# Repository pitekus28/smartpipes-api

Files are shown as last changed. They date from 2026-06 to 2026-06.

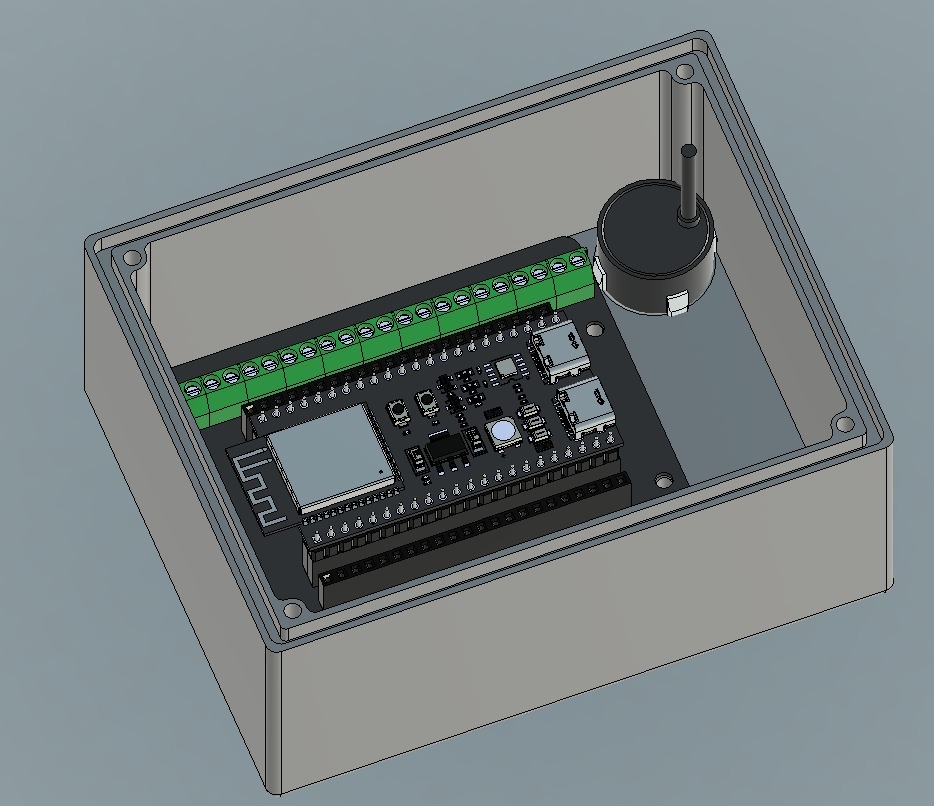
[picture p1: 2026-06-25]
Diseño-3D/Renders/Imagen 2.png

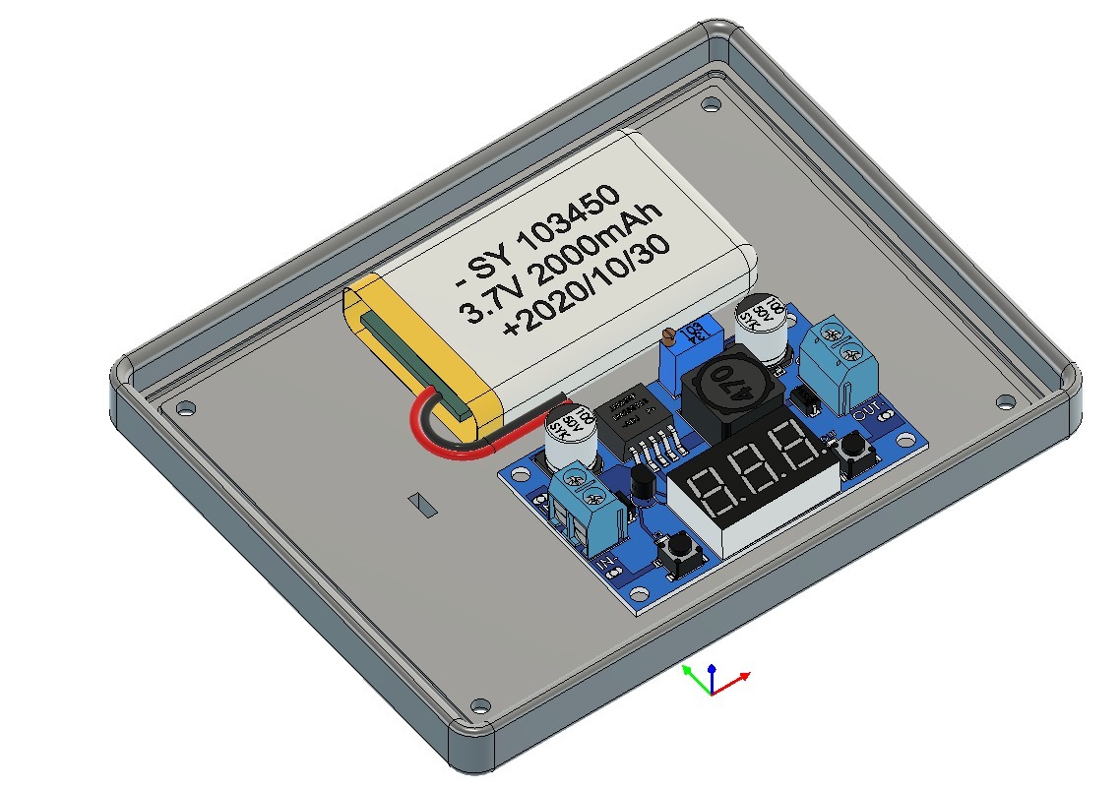
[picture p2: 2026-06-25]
Diseño-3D/Renders/Imagen 3.png

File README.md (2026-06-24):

# SmartPipes

SmartPipes es un prototipo IoT para el monitoreo preventivo de alcantarillados. El sistema mide la distancia física entre el sensor y el nivel de agua, sedimento u obstrucción dentro de una alcantarilla, calcula un porcentaje de llenado, detecta humedad y envía los datos a una base de datos en la nube para visualizarlos en un dashboard web.

## Integrantes

* Javier Fuentes
* Diego Fuentes
* Ignacio Tajmuch
* Felipe Madariaga

## Problema que resuelve

Las obstrucciones en alcantarillados pueden generar rebalses, malos olores, inundaciones y problemas sanitarios. SmartPipes busca detectar acumulación o riesgo de obstrucción de forma temprana mediante sensores instalados en el interior de una alcantarilla.

## Arquitectura del sistema

El flujo del sistema es:

ESP32-S3 → Railway API → Aiven PostgreSQL → Dashboard Web

La ESP32 captura datos del entorno, calcula indicadores y los envía por WiFi a una API desplegada en Railway. La API almacena los datos en una base de datos PostgreSQL en Aiven. El dashboard web permite visualizar el estado actual del sensor y el histórico de mediciones.

## Componentes principales

* ESP32-S3 N16R8
* Sensor ultrasónico impermeable SR04M-2 / AJ-SR04M
* Sensor de humedad/lluvia MH-RD Raindrops Sensor de 2 pines
* Batería LiPo 3.7V 2000mAh
* Módulo Step-Up DC-DC 3.7V a 5V
* Resistencia 10kΩ para pull-down del sensor de humedad
* Cables Dupont
* Protoboard o base de conexión interna

## Sensores y pines usados

### Sensor ultrasónico SR04M-2 / AJ-SR04M

* 5V → 5V/VIN ESP32
* GND → GND ESP32
* TX → GPIO18 ESP32
* RX → Sin conectar

### Sensor humedad MH-RD 2 pines

* Un pin del sensor → 3V3 ESP32
* Otro pin del sensor → GPIO4 ESP32
* GPIO4 → resistencia 10kΩ → GND

## Calibración usada

La alcantarilla se calibró considerando:

* 100 cm o más: alcantarilla limpia, 0% de llenado.
* 20 cm o menos: alcantarilla casi tapada, 100% de llenado.

El porcentaje de llenado se calcula con la distancia física medida por el sensor ultrasónico.

## Estados del sistema

* NORMAL: 0% a 19%
* ATENCION: 20% a 39%
* ALERTA: 40% a 59%
* RIESGO: 60% a 74%
* CRITICO: 75% a 89%
* EMERGENCIA: 90% a 100%

## Dashboard

Dashboard web:

https://smartpipes-api-production.up.railway.app

El dashboard permite visualizar:

* Estado actual del sensor
* Distancia física medida
* Porcentaje de llenado
* Humedad detectada
* Batería
* Histórico mensual
* Gráficas de porcentaje de llenado

## Instrucciones de uso

1. Encender la base de datos Aiven.
2. Activar el deployment en Railway.
3. Conectar la ESP32 a energía.
4. Verificar en el monitor serial que aparezca `Codigo respuesta API: 200`.
5. Abrir el dashboard web.
6. Observar las mediciones en tiempo real.

## Estructura del repositorio

* `firmware/`: código de la ESP32.
* `hardware/`: esquemático, BOM y fotografías del montaje.
* `diseño-3d/`: archivos de Fusion 360, STL, planos y renders.
* `testing/`: protocolo de pruebas, resultados, logs y capturas.
* `docs/`: documentación del proyecto.
* `public/`: dashboard web.
* `server.js`: API backend.

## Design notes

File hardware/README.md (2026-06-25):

# Hardware — SmartPipes

## Descripción

Esta carpeta contiene la documentación del hardware del proyecto SmartPipes. Aquí se incluyen los componentes utilizados en el prototipo, el esquemático de conexiones y la información necesaria para comprender cómo fue implementado físicamente el sistema.

El hardware fue diseñado para capturar datos reales del entorno mediante sensores, procesarlos con una ESP32-S3 y alimentar el sistema de forma portátil, manteniendo una arquitectura coherente con el problema abordado: el monitoreo preventivo de ductos y alcantarillados.

---

## Contenido de la carpeta

### 1. BOM (Bill of Materials)

La lista de materiales resume los componentes utilizados para construir el prototipo, junto con su cantidad, especificación, función y costo aproximado.

Incluye elementos principales como:

* ESP32-S3 N16R8
* sensor ultrasónico impermeable AJ-SR04M / SR04M
* sensor de humedad MH-RD
* batería LiPo
* módulo Step-Up DC-DC
* cables, resistencia pull-down, tornillos y materiales de fabricación

La BOM permite estimar el costo total del prototipo y documentar la viabilidad de replicación del sistema.

### 2. Esquemático de conexiones

El esquemático documenta la conexión entre la ESP32-S3, los sensores y el sistema de alimentación.

Se detallan:

* alimentación desde batería LiPo hacia el módulo Step-Up
* entrega de 5V a la ESP32 y al sensor ultrasónico
* lectura del sensor ultrasónico mediante GPIO18
* lectura del sensor de humedad mediante GPIO4
* uso de resistencia pull-down de 10kΩ para evitar falsos positivos en el sensor de humedad
* conexión común de tierras (GND) en todo el sistema

---

## Arquitectura de hardware

El sistema físico se compone de tres subsistemas principales:

### 1. Control y procesamiento

La **ESP32-S3 N16R8** actúa como controlador principal. Se encarga de:

* leer los sensores,
* calcular el porcentaje de llenado,
* clasificar el estado del ducto,
* y enviar los datos al sistema web mediante WiFi.

### 2. Sensado

El prototipo utiliza dos sensores:

* **AJ-SR04M / SR04M-2**: mide la distancia física al fondo del ducto o a una obstrucción.
* **MH-RD Raindrops**: detecta humedad o presencia de agua como variable complementaria.

La elección del sensor ultrasónico impermeable fue especialmente importante para hacer coherente el sistema con un contexto húmedo o expuesto al agua.

### 3. Alimentación

La energía del sistema proviene de una **batería LiPo de 3.7V**, cuyo voltaje es elevado mediante un **módulo Step-Up DC-DC** para alimentar correctamente la ESP32 y el sensor ultrasónico.

---

## Consideraciones técnicas importantes

### Sensor de humedad

El sensor MH-RD requiere una **resistencia pull-down de 10kΩ** entre GPIO4 y GND. Esta resistencia evita que el pin quede flotando, lo que podría generar lecturas falsas de humedad.

### Sensor ultrasónico

El sensor AJ-SR04M fue elegido por su mayor pertinencia para un sistema expuesto a agua o humedad, en comparación con sensores ultrasónicos más básicos como el HC-SR04.

### GND común

Todos los negativos del sistema deben compartir tierra común:

* GND de la ESP32
* GND del sensor ultrasónico
* negativo de batería
* salida negativa del Step-Up
* GND de la resistencia pull-down

Esto es fundamental para asegurar lecturas estables y un funcionamiento correcto del sistema.

---

## Justificación general del hardware

Los componentes seleccionados permiten construir un prototipo funcional, portátil y técnicamente coherente con el problema del proyecto. El sistema combina:

* procesamiento con conectividad WiFi,
* medición física de nivel u obstrucción,
* detección complementaria de humedad,
* y alimentación autónoma mediante batería.

Además, el montaje fue pensado para integrarse dentro de un encapsulado fabricado en 3D, con fijaciones desmontables y acceso a componentes internos para reparación o ajuste.

---

## Archivos esperados en esta carpeta

* `BOM.md`, `BOM.xlsx` o equivalente
* `esquematico.pdf` o imagen del esquemático
* fotografías del prototipo ensamblado
* documentación complementaria de conexiones si aplica

---

## Observaciones

La documentación contenida en esta carpeta permite entender, replicar y justificar la implementación física del prototipo SmartPipes dentro del contexto del curso TEI201.

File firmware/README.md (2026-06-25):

# Firmware — SmartPipes

## Descripción

Esta carpeta contiene el firmware principal del sistema SmartPipes. El programa está desarrollado para una **ESP32-S3** y se encarga de capturar datos del entorno, procesarlos y enviarlos a la nube para su visualización en un dashboard web.

El firmware mide la distancia interna de un ducto mediante un sensor ultrasónico impermeable, detecta presencia de humedad, calcula el porcentaje de llenado y clasifica el estado del sistema según niveles de riesgo.

---

## Funciones principales del firmware

El código implementa las siguientes tareas:

* conexión de la ESP32 a una red WiFi
* lectura del sensor ultrasónico AJ-SR04M / SR04M-2
* filtrado básico mediante promedio de múltiples lecturas
* lectura del sensor de humedad MH-RD
* cálculo del porcentaje de llenado del ducto
* clasificación del estado del sistema
* impresión de resultados en el monitor serial
* envío de datos en formato JSON a una API desplegada en Railway

---

## Variables que genera el sistema

El firmware obtiene y procesa las siguientes variables:

* **distancia_cm**: distancia medida entre el sensor y el fondo u obstrucción
* **porcentaje_lleno**: estimación del nivel de llenado del ducto
* **humedad**: presencia o ausencia de humedad detectada
* **estado**: clasificación del ducto según el nivel de riesgo
* **bateria_voltaje**: valor de batería enviado como referencia

---

## Calibración utilizada

La lógica del sistema utiliza dos referencias físicas:

* **100 cm o más** → ducto limpio → **0% lleno**
* **20 cm o menos** → ducto casi tapado → **100% lleno**

Con esto, el firmware transforma una distancia física en una estimación de llenado útil para interpretar el estado del ducto.

---

## Estados definidos

El sistema clasifica el ducto en los siguientes niveles:

| Estado | Interpretación |
| --- | --- |
| NORMAL | Ducto despejado  |
| ATENCION | Acumulación leve |
| ALERTA | Posible bloqueo  |
| RIESGO | Obstrucción alta |
| CRITICO | Casi colapsado |
| EMERGENCIA | Tapado total |
| ERROR | Falla de sensor  |

---

## Hardware esperado por el firmware

### Microcontrolador

* ESP32-S3 N16R8

### Sensor ultrasónico

* AJ-SR04M / SR04M-2

### Sensor de humedad

* MH-RD Raindrops de 2 pines

### Otros elementos

* resistencia pull-down de 10kΩ
* batería LiPo 3.7V
* módulo Step-Up DC-DC 3.7V a 5V

---

## Pines utilizados

### Sensor ultrasónico

* `GPIO18` → señal del sensor ultrasónico

### Sensor de humedad

* `GPIO4` → lectura del sensor MH-RD

---

## Flujo de funcionamiento

1. La ESP32 se conecta a WiFi.
2. El sensor ultrasónico mide la distancia.
3. El sistema calcula el porcentaje de llenado.
4. El sensor de humedad detecta presencia de agua o conducción.
5. Se evalúa el estado del ducto.
6. Los datos se imprimen en el monitor serial.
7. Se envían a la API en Railway.
8. El ciclo se repite aproximadamente cada 10 segundos.

---

## Servicios externos utilizados

El firmware está preparado para trabajar con:

* una **API en Railway**
* una **base de datos PostgreSQL en Aiven**
* un **dashboard web SmartPipes**

---

## Cómo cargar el firmware

1. Abrir el archivo `.ino` en Arduino IDE.
2. Seleccionar la placa ESP32 correspondiente.
3. Revisar las credenciales de WiFi y la URL de la API.
4. Verificar la conexión de sensores y alimentación.
5. Cargar el código en la ESP32.
6. Abrir el monitor serial a **115200 baudios** para revisar el funcionamiento.

---

## Archivos esperados en esta carpeta

* `smart_pipes.ino` o archivo principal equivalente
* este `README.md`

---

## Observaciones

El firmware fue adaptado para el uso de un sensor ultrasónico impermeable, más coherente con el contexto del proyecto, orientado al monitoreo de ductos y alcantarillas con posible presencia de humedad o agua.

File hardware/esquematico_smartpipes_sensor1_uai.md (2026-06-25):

smartpipes_sensor1_UAI_esquematico_final
# Esquemático de conexiones SmartPipes

## ESP32-S3 N16R8

La ESP32-S3 es el controlador principal del sistema. Lee los sensores, calcula el porcentaje de llenado y envía los datos al dashboard web mediante WiFi.

## Alimentación

| Componente | Pin | Conexión |
|---|---|---|
| Batería LiPo 3.7V | + | IN+ Step-Up |
| Batería LiPo 3.7V | - | IN- Step-Up |
| Step-Up DC-DC | OUT+ 5V | 5V/VIN ESP32 |
| Step-Up DC-DC | OUT- GND | GND ESP32 |

## Sensor ultrasónico SR04M-2 / AJ-SR04M

| Pin sensor | Conexión |
|---|---|
| 5V | 5V/VIN ESP32 |
| GND | GND ESP32 |
| TX | GPIO18 ESP32 |
| RX | Sin conectar |

## Sensor humedad MH-RD Raindrops 2 pines

| Pin / elemento | Conexión |
|---|---|
| Pin 1 sensor humedad | 3V3 ESP32 |
| Pin 2 sensor humedad | GPIO4 ESP32 |
| Resistencia 10kΩ | Entre GPIO4 y GND |

## Nota importante

Todos los GND del sistema deben estar conectados en común:

- GND ESP32
- GND del sensor ultrasónico
- OUT- del Step-Up
- Negativo de batería
- GND de la resistencia pull-down

## Diagrama simplificado

```txt
Batería LiPo 3.7V
        |
        v
Step-Up DC-DC 3.7V a 5V
        |
        v
ESP32-S3 N16R8
        |
        |-- GPIO18 -> TX Sensor ultrasónico SR04M-2
        |-- 5V/VIN -> 5V Sensor ultrasónico
        |-- GND    -> GND Sensor ultrasónico
        |
        |-- GPIO4  -> Sensor humedad MH-RD
        |-- 3V3    -> Sensor humedad MH-RD
        |-- GPIO4  -> Resistencia 10kΩ -> GND

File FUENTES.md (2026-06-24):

# FUENTES.md

Este documento declara las librerías, plataformas, herramientas externas y uso de inteligencia artificial utilizados en el desarrollo del prototipo SmartPipes.

## Librerías utilizadas

| Librería | Uso en el proyecto | Fuente |
|---|---|---|
| WiFi.h | Conexión WiFi de la ESP32 | Librería incluida en el core de ESP32 para Arduino |
| HTTPClient.h | Envío de datos HTTP/HTTPS desde ESP32 hacia la API | Librería incluida en el core de ESP32 para Arduino |
| WiFiClientSecure.h | Conexión HTTPS segura desde la ESP32 hacia Railway | Librería incluida en el core de ESP32 para Arduino |
| express | Servidor backend en Node.js para recibir datos y servir dashboard | https://www.npmjs.com/package/express |
| pg | Conexión entre Node.js y PostgreSQL | https://www.npmjs.com/package/pg |
| cors | Permite solicitudes entre cliente y servidor | https://www.npmjs.com/package/cors |
| dotenv | Manejo de variables de entorno | https://www.npmjs.com/package/dotenv |
| Chart.js | Visualización de gráficos históricos en el dashboard | https://www.chartjs.org/ |

## Plataformas utilizadas

| Plataforma | Uso en el proyecto |
|---|---|
| Arduino IDE | Desarrollo y carga del firmware en la ESP32 |
| GitHub | Repositorio del proyecto |
| Railway | Despliegue de la API y dashboard web |
| Aiven PostgreSQL | Base de datos persistente para almacenar mediciones |
| Fusion 360 | Diseño 3D de carcasa y gemelo digital |
| Fritzing / herramienta equivalente | Desarrollo del esquemático de conexión |

## Código externo adaptado

No se copió código externo completo desde repositorios de terceros. Se utilizaron ejemplos generales de conexión WiFi, solicitudes HTTP y manejo de servidores Express como referencia conceptual, adaptándolos al caso específico de SmartPipes.

## Uso de Inteligencia Artificial

### Desarrollo del firmware ESP32

- Herramienta: ChatGPT
- Uso: Apoyo para estructurar y comentar el firmware de la ESP32.
- Adaptación: El código fue ajustado al hardware real utilizado: ESP32-S3 N16R8, sensor ultrasónico SR04M-2 usando TX como lectura hacia GPIO18, sensor de humedad MH-RD en GPIO4 y envío de datos hacia Railway.
- Comprensión: El equipo entiende que el firmware mide distancia, calcula porcentaje de llenado, evalúa un estado mediante umbrales, detecta humedad y envía un JSON por HTTPS a la API.

### Desarrollo de API y dashboard

- Herramienta: ChatGPT
- Uso: Apoyo en la creación de la API con Node.js, Express y PostgreSQL, además del dashboard web.
- Adaptación: El backend fue configurado con la base de datos Aiven PostgreSQL del proyecto y desplegado en Railway. El dashboard fue adaptado para mostrar Sensor 1 UAI, distancia física, porcentaje de llenado, humedad, batería, estado e histórico mensual.
- Comprensión: El equipo entiende que Railway recibe las mediciones desde la ESP32, las guarda en Aiven y luego entrega los datos al dashboard mediante rutas API.

### Documentación y organización de GitHub

- Herramienta: ChatGPT
- Uso: Apoyo en la redacción de README.md, FUENTES.md y estructura de carpetas del repositorio.
- Adaptación: La documentación fue ajustada al proyecto SmartPipes, sus componentes reales, conexiones y flujo de datos.
- Comprensión: El equipo entiende la función de cada carpeta, archivo y plataforma dentro del sistema completo.

## Declaración final

El equipo declara que las herramientas externas e inteligencia artificial fueron utilizadas como apoyo para acelerar el desarrollo, depuración y documentación del proyecto. Las decisiones técnicas, integración física, pruebas y adaptación al problema fueron realizadas por el equipo.

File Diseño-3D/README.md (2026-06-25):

# Diseño 3D — SmartPipes

## Descripción

Esta carpeta contiene los archivos de diseño 3D del proyecto SmartPipes. Aquí se incluye el modelo del encapsulado desarrollado en Fusion 360 y las exportaciones utilizadas para documentar y fabricar la carcasa del prototipo.

El diseño 3D fue desarrollado para alojar los componentes del sistema, proteger el hardware y permitir un montaje ordenado, considerando además acceso a elementos internos para mantenimiento y reparación.

---

## Contenido de la carpeta

### 1. Archivo fuente de Fusion 360

El archivo `.f3d` corresponde al modelo principal del encapsulado desarrollado en Fusion 360. Este archivo permite revisar el diseño paramétrico, editar dimensiones y visualizar el ensamble del sistema.

### 2. Archivo STL

El archivo `.stl` corresponde a la exportación del modelo 3D para fabricación o visualización de la carcasa.

### 3. Planos técnicos

Si se incluyen, los planos en PDF documentan las vistas principales, cotas y escala del encapsulado, permitiendo comunicar su geometría de forma técnica.

### 4. Renders o capturas

Si se incluyen, los renders muestran el encapsulado desde distintas vistas y ayudan a comunicar visualmente el diseño del sistema.

---

## Función del encapsulado

El encapsulado fue diseñado para:

* proteger los componentes electrónicos del sistema
* integrar físicamente sensores, microcontrolador y alimentación
* permitir el montaje de la carcasa mediante fijaciones mecánicas
* facilitar el acceso a componentes internos sin destruir el ensamble
* representar en 3D la solución física del proyecto

---

## Relación con el hardware

El diseño 3D no fue planteado solo como una carcasa estética, sino como parte funcional del sistema SmartPipes. Su propósito es contener y organizar los componentes del prototipo de forma coherente con el problema abordado, considerando un entorno asociado a ductos, humedad y necesidad de mantenimiento.

---

## Archivos esperados en esta carpeta

* archivo fuente Fusion 360 (`.f3d` o `.f3z`)
* archivo STL del encapsulado
* planos técnicos en PDF
* renders o capturas del modelo
* exportaciones adicionales si existen

---

## Observaciones

Para la evaluación del proyecto, es importante que el diseño 3D represente el sistema de forma funcional y no solo estética. En caso de contar con un ensamble completo, el modelo debe reflejar cómo los componentes internos se integran físicamente dentro del encapsulado.

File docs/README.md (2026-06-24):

# Documentación

Esta carpeta contiene la presentación final, informes, avances, documentación general del proyecto y archivos complementarios para la entrega.

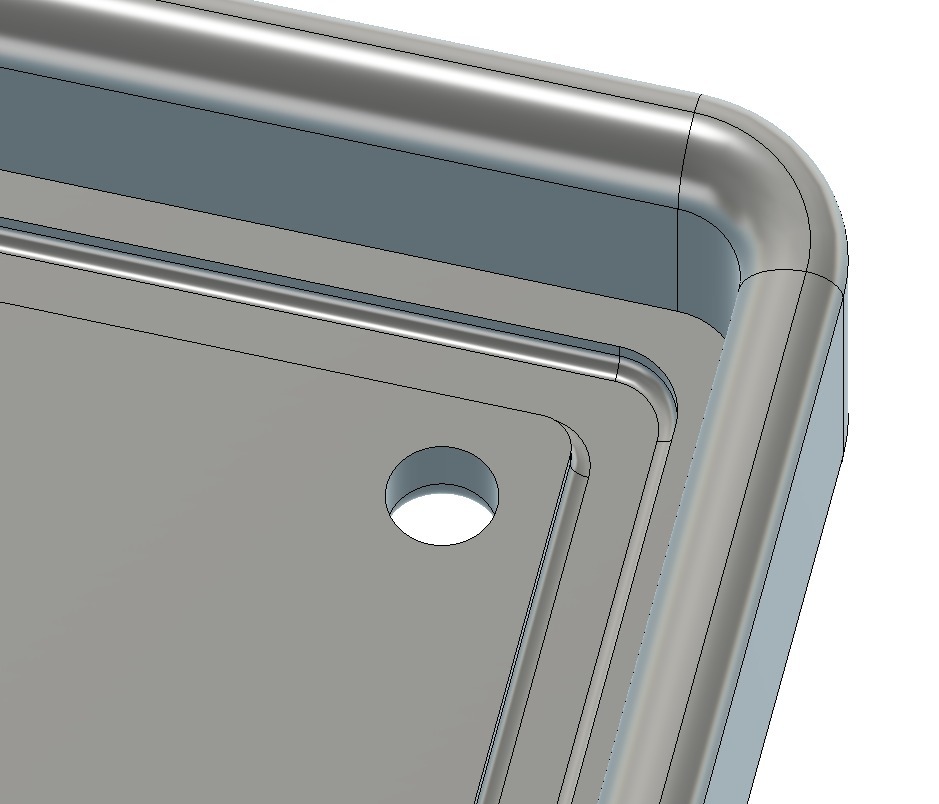
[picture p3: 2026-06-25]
Diseño-3D/Renders/Imagen 4.png

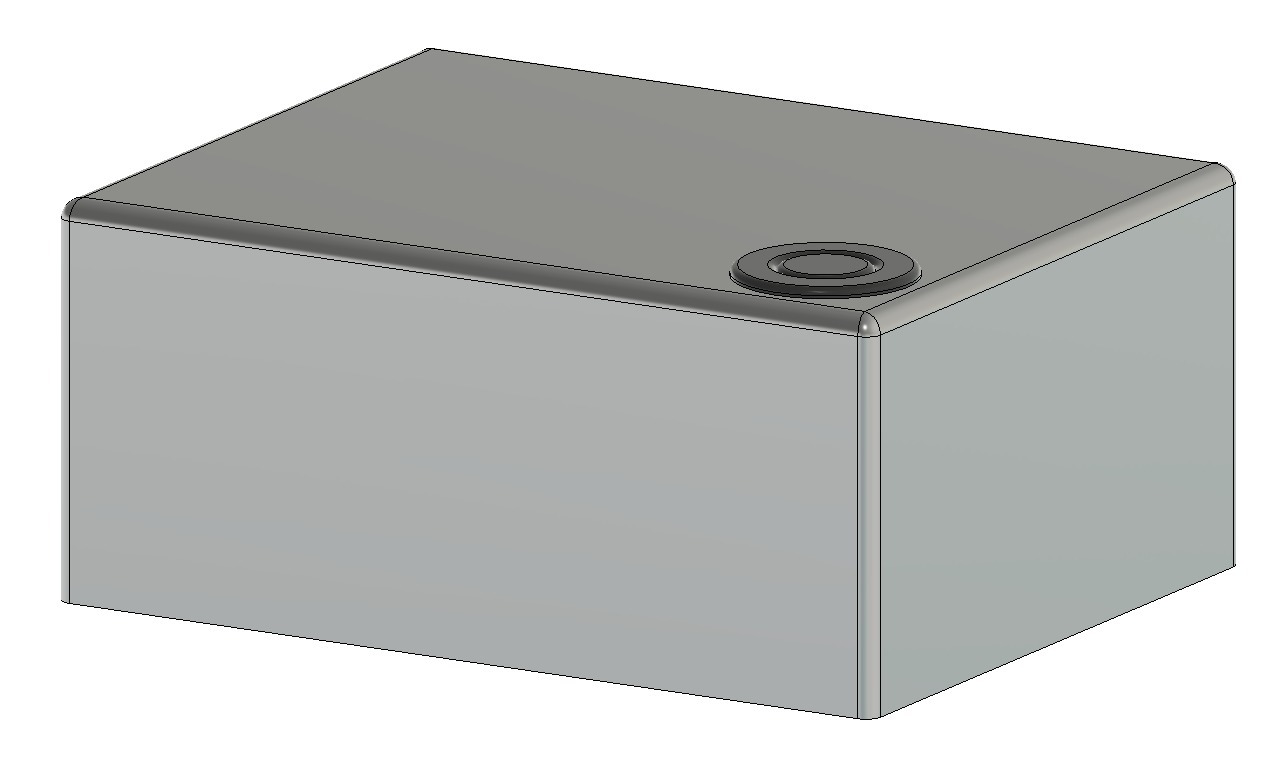
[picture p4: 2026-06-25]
Diseño-3D/Renders/Imagen 1.png

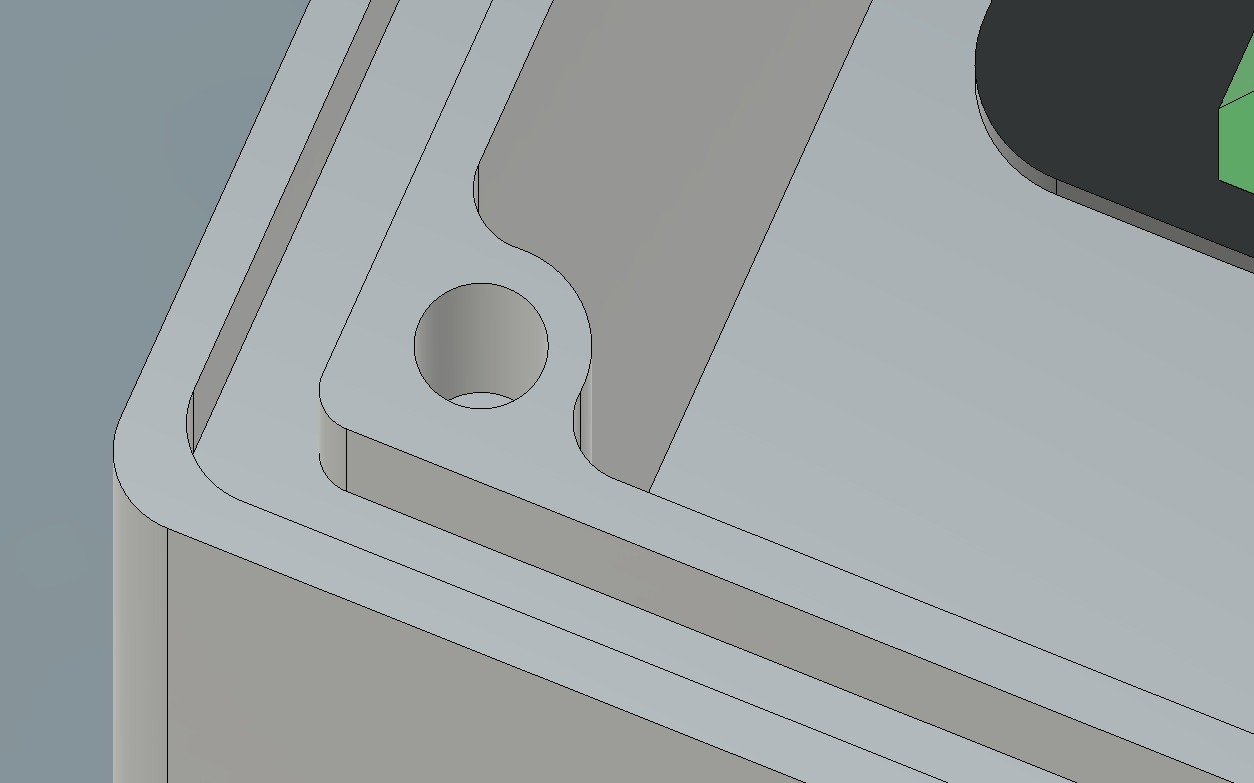
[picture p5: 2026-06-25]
Diseño-3D/Renders/Imagen 5.png

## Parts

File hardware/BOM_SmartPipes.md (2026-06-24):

# BOM SmartPipes

BOM significa Bill of Materials o lista de materiales. Esta tabla resume los componentes utilizados para construir el prototipo SmartPipes.

| Componente | Cantidad | Especificación | Función | Costo aprox. USD |
|---|---:|---|---|---:|
| ESP32-S3 N16R8 | 1 | Microcontrolador con WiFi | Control del sistema y envío de datos | 5.70 |
| Sensor ultrasónico impermeable AJ-SR04M / SR04M | 1 | Sensor de distancia impermeable | Medir distancia al agua, sedimento u obstrucción | 10.87 |
| Batería LiPo | 1 | 3.7V 2000mAh | Alimentación del prototipo | 10.00 |
| Resistencia | 1 | 10kΩ | Pull-down para sensor de humedad | 1.00 |
| Protoboard / placa de desarrollo | 1 | Placa pequeña de conexión | Montaje interno del circuito | 3.33 |
| Cables Dupont | 20 aprox. | Cables de conexión | Conexión entre ESP32, sensores y alimentación | 2.37 |
| Sensor humedad/lluvia | 1 | MH-RD Raindrops Sensor 2 pines | Detección de humedad o presencia de agua | 2.50 |
| Módulo Step-Up DC-DC | 1 | 3.7V a 5V | Elevar voltaje de batería a 5V | 2.00 |
| O-ring | 5 | Junta circular de goma | Sellado mecánico del sensor/carcasa | 0.46 |
| Tornillos cabeza plana | 16 aprox. | M2/M3 10 mm | Fijación de tapa y componentes internos | 2.30 |
| Filamento PLA | 1 | Material de impresión 3D | Fabricación de carcasa | 16.00 |
| Pasta de soldar | 1 | Soldadura 60/40 | Unión eléctrica de cables/componentes | — |
| Silicona impermeable | 1 | Sellador para juntas | Impermeabilización del prototipo | — |

## Costo total aproximado

35.97 USD

## Nota

Los valores son aproximados y corresponden a precios referenciales de aliexpress utilizados para estimar el costo del prototipo. Algunos materiales, como soldadura, silicona y filamento PLA, pueden variar según disponibilidad y cantidad utilizada.

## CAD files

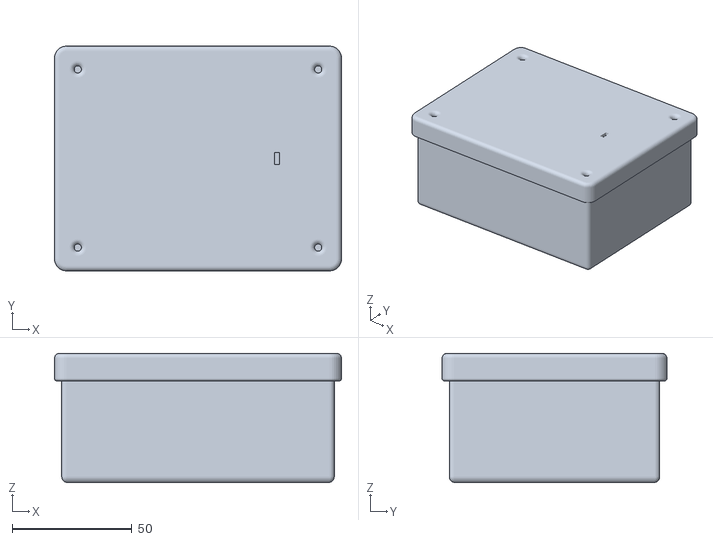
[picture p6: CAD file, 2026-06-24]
Diseño-3D/Encapsulado.stl
120.0 x 94.0 x 54.0

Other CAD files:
Diseño-3D/Encapsulado f3d (online).step

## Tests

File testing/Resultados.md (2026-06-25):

# Resultados y Validación — SmartPipes

## 1. Resultados obtenidos

Durante las pruebas, el sistema logró capturar datos reales de distancia y visualizarlos correctamente en el dashboard. Las mediciones registradas muestran que el sistema cambia de estado de forma coherente según la distancia física detectada y el porcentaje de llenado calculado.

Los siguientes registros corresponden a datos reales medidos durante la validación del prototipo:

| Fecha y hora | Sensor | Distancia (cm) | Porcentaje de llenado | Humedad | Estado |
| --- | --- | ---: | ---: | --- | --- |
| 24-06-2026, 3:14:52 p. m. | Sensor 1 UAI | 84.60 | 19.30% | SI | ATENCION |
| 24-06-2026, 4:00:17 p. m. | Sensor 1 UAI | 63.10 | 46.10% | NO | ALERTA |
| 24-06-2026, 4:19:01 p. m. | Sensor 1 UAI | 22.70 | 96.60% | NO | EMERGENCIA |
| 24-06-2026, 4:56:38 p. m. | Sensor 1 UAI | 40.90 | 73.90% | NO | CRITICO |

## 2. Interpretación de resultados

Los datos muestran que el sistema responde de manera lógica frente a distintos niveles de obstrucción:

* Con **84.60 cm**, el sistema mostró **ATENCION**, indicando una condición de acumulación leve.
* Con **63.10 cm**, el sistema cambió a **ALERTA**, mostrando un nivel intermedio de riesgo.
* Con **40.90 cm**, el sistema mostró **CRITICO**, reflejando una condición cercana al colapso.
* Con **22.70 cm**, el sistema alcanzó el estado **EMERGENCIA**, correspondiente a una condición de obstrucción severa.

Estos resultados demuestran que, a medida que la distancia libre disminuye, el porcentaje de llenado aumenta y el sistema eleva el nivel de riesgo.

La humedad se interpreta como una variable complementaria. El estado principal del ducto se determina por la distancia y el porcentaje de llenado, mientras que la humedad ayuda a contextualizar si existe presencia de agua o conducción en el sensor MH-RD.

## 3. Comportamiento observado del sistema

El sensor ultrasónico respondió correctamente a cambios físicos de distancia. Al acercar un objeto al sensor, la distancia medida disminuyó y el porcentaje de llenado aumentó. Esto confirma que el principio de medición es adecuado para representar acumulación o bloqueo dentro de un ducto.

El tiempo de respuesta observado fue adecuado para los fines del prototipo. La información capturada por la ESP32 fue visible en el dashboard en una escala de tiempo útil para monitoreo preventivo.

Durante el desarrollo también se identificaron fuentes de error relevantes:

* posibles falsos positivos del sensor de humedad cuando el pin quedaba flotante,
* dependencia del orden de encendido de servicios cloud,
* y necesidad de recalibrar la referencia de ducto limpio según las dimensiones reales del caso.

## 4. Falla principal encontrada y solución aplicada

La principal dificultad del desarrollo fue el cambio del sensor ultrasónico originalmente utilizado.

Inicialmente el sistema fue adaptado para trabajar con el sensor **HC-SR04**. Sin embargo, dado que el proyecto está orientado a monitoreo de alcantarillas y ductos con posible presencia de humedad o agua, ese sensor no era técnicamente la mejor alternativa para una aplicación realista.

Por esta razón se decidió reemplazarlo por el sensor impermeable **AJ-SR04M**. Este cambio implicó:

* modificar parte del código ya adaptado,
* reajustar la lógica de lectura,
* recalibrar el sistema,
* y volver a integrar el prototipo completo.

Además, durante el desarrollo se detectaron y corrigieron otras fallas menores:

| Falla encontrada | Causa | Solución aplicada |
| --- | --- | --- |
| Humedad siempre marcaba SI | GPIO4 flotante | Se agregó resistencia pull-down de 10kΩ |
| Dashboard no cargaba correctamente si los servicios estaban detenidos | Dependencia de Railway y Aiven | Se definió orden de encendido: Aiven → Railway → ESP32 |
| Registros anteriores afectaban pruebas nuevas | Base de datos con mediciones acumuladas | Se limpiaron mediciones previas antes de validar |
| Porcentaje no representaba bien el ducto real | Calibración inicial distinta a la condición física medida | Se ajustó la referencia limpia a 100 cm |

## 5. Validación contra el problema original

El problema original identificado por SmartPipes corresponde a la falta de monitoreo preventivo de alcantarillados y desagües urbanos. En muchos casos, la mantención ocurre de forma reactiva, cuando la obstrucción o acumulación ya generó inundación, malos olores o problemas sanitarios.

SmartPipes valida una solución preventiva porque permite detectar señales tempranas de obstrucción antes de que el sistema colapse. El prototipo mide distancia física dentro del ducto, calcula porcentaje de llenado y clasifica el nivel de riesgo. Estos datos transforman una medición cruda en una decisión práctica.

Por ejemplo:

| Estado | Decisión sugerida |
| --- | --- |
| NORMAL | No requiere intervención |
| ATENCION | Monitorear evolución |
| ALERTA | Programar inspección preventiva |
| RIESGO | Priorizar revisión en terreno |
| CRITICO | Ejecutar limpieza urgente |
| EMERGENCIA | Intervenir inmediatamente |

De esta forma, el sistema cumple el ciclo IoT requerido por el proyecto:

**Dispositivo captura datos → genera información → permite tomar decisiones**

La ESP32 captura datos reales mediante sensores, el sistema los almacena, el dashboard visualiza el estado actual e histórico, y los niveles de alerta permiten decidir cuándo monitorear, inspeccionar o intervenir un punto crítico.

## 6. Conclusión

Las pruebas realizadas muestran que SmartPipes cumple con el objetivo principal del proyecto: entregar información preventiva sobre el estado de un alcantarillado mediante un sistema IoT funcional.

El prototipo no resuelve físicamente una obstrucción, pero sí permite detectar condiciones de riesgo antes de que se produzca una falla mayor. Esto entrega valor para una gestión más preventiva y menos reactiva del problema.

Como mejoras futuras se propone:

* implementar medición real de porcentaje de batería mediante divisor de voltaje,
* mejorar la impermeabilización del encapsulado,
* instalar más sensores para validar el sistema en múltiples puntos,
* agregar alertas automáticas por correo, WhatsApp o panel municipal,
* incorporar geolocalización de sensores en un mapa.

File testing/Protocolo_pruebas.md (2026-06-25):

# Protocolo de Pruebas — SmartPipes

## 1. Objetivo de las pruebas

El objetivo de estas pruebas es validar que el prototipo SmartPipes funciona como un sistema IoT capaz de:

1. Medir la distancia física dentro de una alcantarilla o ducto simulado.
2. Calcular un porcentaje de llenado asociado al nivel de obstrucción.
3. Clasificar el estado del ducto mediante umbrales de riesgo.
4. Detectar presencia de humedad mediante el sensor MH-RD.
5. Enviar los datos por WiFi hacia una API desplegada en Railway.
6. Guardar las mediciones en una base de datos PostgreSQL en Aiven.
7. Visualizar los datos en un dashboard web con histórico y estados interpretables.

Estas pruebas buscan comprobar que el sistema no solo captura datos, sino que transforma esas mediciones en información útil para la toma de decisiones preventivas.

## 2. Condiciones de prueba

Las pruebas se realizaron con el prototipo SmartPipes Sensor 1 UAI compuesto por:

* ESP32-S3 N16R8
* Sensor ultrasónico impermeable SR04M-2 / AJ-SR04M
* Sensor de humedad MH-RD Raindrops de 2 pines
* Resistencia pull-down de 10kΩ para el sensor de humedad
* Batería LiPo 3.7V 2000mAh
* Módulo Step-Up DC-DC 3.7V a 5V
* API en Railway
* Base de datos PostgreSQL en Aiven
* Dashboard web SmartPipes

La calibración usada para el prototipo fue:

| Condición física | Distancia medida | Porcentaje de llenado |
| --- | ---: | ---: |
| Alcantarilla limpia o despejada | 100 cm o más | 0% |
| Alcantarilla casi tapada | 20 cm o menos | 100% |

El sistema calcula el porcentaje de llenado a partir de la distancia física medida por el sensor ultrasónico. A menor distancia, mayor es el porcentaje de llenado, porque significa que el agua, basura o sedimento se encuentra más cerca del sensor.

## 3. Procedimiento de prueba

### Prueba 1: Lectura del sensor ultrasónico

**Objetivo:** comprobar que el sensor ultrasónico mide distancia física de forma estable.

**Procedimiento:**

1. Encender la ESP32.
2. Verificar conexión WiFi desde el monitor serial.
3. Ubicar un objeto frente al sensor a distintas distancias.
4. Registrar las lecturas mostradas en el dashboard.
5. Confirmar que la distancia medida cambia al acercar o alejar el objeto.
6. Verificar que el dato enviado a la API corresponde a la distancia medida.

**Criterio de éxito:**
La prueba se considera exitosa si el sensor entrega valores coherentes y variables según la distancia física del objeto, y si estos valores aparecen correctamente en el dashboard.

### Prueba 2: Cálculo de porcentaje de llenado

**Objetivo:** validar que la distancia medida se transforma correctamente en porcentaje de llenado.

**Procedimiento:**

1. Simular una condición despejada con una distancia cercana o superior a 100 cm.
2. Confirmar que el porcentaje de llenado se aproxima a 0%.
3. Simular una condición intermedia con una distancia entre 60 y 80 cm.
4. Confirmar que el porcentaje de llenado aumenta.
5. Simular una condición crítica acercando el objeto al sensor, bajo 30 cm.
6. Confirmar que el porcentaje de llenado se aproxima a valores altos.

**Criterio de éxito:**
La prueba se considera exitosa si el porcentaje aumenta cuando la distancia disminuye, representando correctamente el nivel de obstrucción.

### Prueba 3: Clasificación de estado

**Objetivo:** verificar que el sistema clasifica correctamente el estado del ducto.

**Estados utilizados:**

| Porcentaje de llenado | Estado | Interpretación |
| ---: | --- | --- |
| 0% - 19% | NORMAL | Ducto despejado  |
| 20% - 39% | ATENCION | Acumulación leve |
| 40% - 59% | ALERTA | Posible bloqueo  |
| 60% - 74% | RIESGO | Obstrucción alta |
| 75% - 89% | CRITICO | Casi colapsado |
| 90% - 100% | EMERGENCIA | Tapado total |

**Procedimiento:**

1. Probar distintas distancias frente al sensor.
2. Observar el porcentaje calculado.
3. Verificar que el estado mostrado corresponde al rango esperado.
4. Revisar que el mismo estado se guarde en la base de datos.
5. Confirmar que el dashboard muestra el último estado registrado.

**Criterio de éxito:**
La prueba se considera exitosa si el estado cambia de forma coherente con el porcentaje de llenado y permite diferenciar entre ducto normal, atención, alerta, riesgo, crítico y emergencia.

### Prueba 4: Sensor de humedad

**Objetivo:** validar la lectura del sensor de humedad MH-RD.

**Procedimiento:**

1. Conectar el sensor MH-RD a 3V3 y GPIO4.
2. Conectar una resistencia de 10kΩ entre GPIO4 y GND.
3. Observar el valor del sensor en seco.
4. Probar el sensor con presencia de agua o puenteando la señal para verificar la lectura.
5. Confirmar que el dashboard cambia entre humedad detectada: SI / NO.

**Criterio de éxito:**
La prueba se considera exitosa si el sistema logra diferenciar entre ausencia y presencia de conducción eléctrica en el sensor. Durante las pruebas se comprobó que la resistencia pull-down evita falsos positivos cuando el pin queda flotante.

### Prueba 5: Envío de datos a la nube

**Objetivo:** comprobar que la ESP32 envía datos correctamente a la API en Railway.

**Procedimiento:**

1. Verificar que Aiven esté en estado activo.
2. Verificar que Railway esté desplegado correctamente.
3. Conectar la ESP32 a WiFi.
4. Observar el dashboard.
5. Confirmar que cada nueva medición aparece registrada en el sistema.

**Criterio de éxito:**
La prueba se considera exitosa si las mediciones capturadas por la ESP32 quedan visibles en el dashboard y persisten en el sistema.

### Prueba 6: Dashboard e histórico

**Objetivo:** verificar que el dashboard permite interpretar el estado actual e histórico del sistema.

**Procedimiento:**

1. Abrir el dashboard web.
2. Observar la tarjeta principal del Sensor 1 UAI.
3. Verificar distancia, porcentaje, humedad, batería y estado.
4. Revisar la tabla de últimas mediciones.
5. Confirmar que al cambiar la distancia física, el dashboard actualiza los datos.

**Criterio de éxito:**
La prueba se considera exitosa si el dashboard muestra información actualizada, comprensible y útil para identificar estados de riesgo.

## 4. Evidencia asociada

La evidencia visual de estas pruebas se encuentra en la carpeta `testing/evidencia/`, donde se incluyen capturas del dashboard correspondientes a distintos estados observados del sistema:

* ATENCION
* ALERTA
* CRITICO
* EMERGENCIA

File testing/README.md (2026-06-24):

# Testing

Esta carpeta contiene el protocolo de pruebas, resultados obtenidos, análisis de fallas y soluciones implementadas durante el desarrollo del proyecto.

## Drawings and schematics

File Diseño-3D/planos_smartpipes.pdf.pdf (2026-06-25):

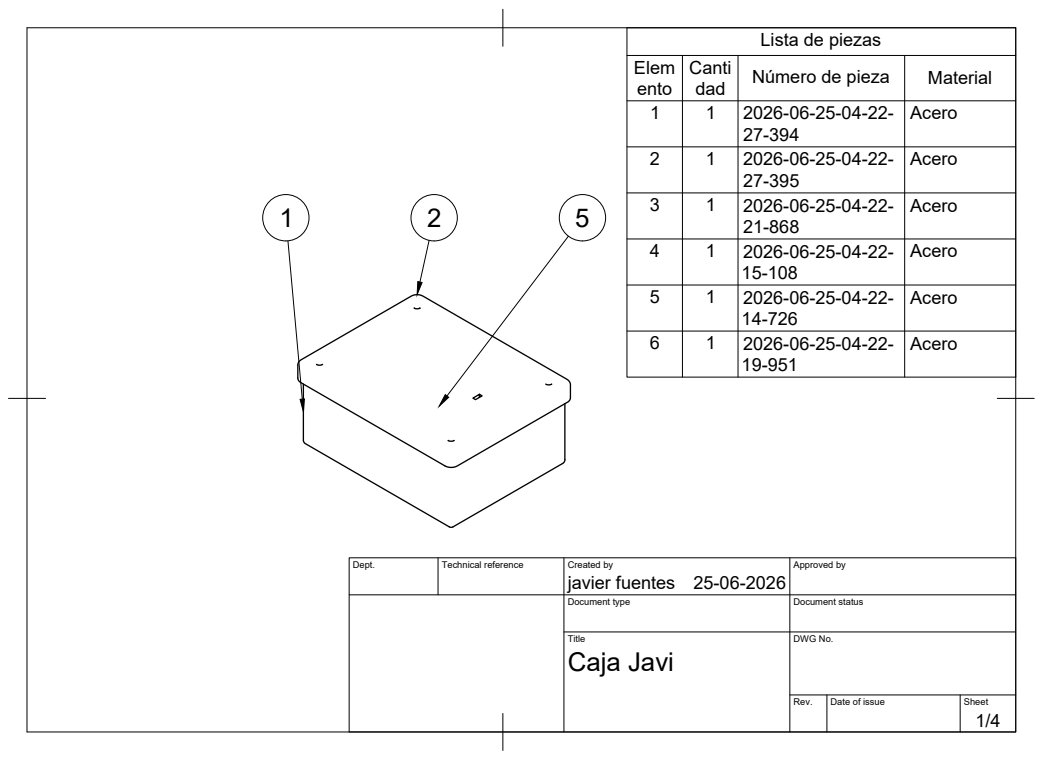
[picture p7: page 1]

Lista de piezas

Elem ento | Canti dad | Número de pieza | Material

1 | 1 | 2026-06-25-04-22-27-394 | Acero

2 | 1 | 2026-06-25-04-22-27-395 | Acero

3 | 1 | 2026-06-25-04-22-21-868 | Acero

4 | 1 | 2026-06-25-04-22-15-108 | Acero

5 | 1 | 2026-06-25-04-22-14-726 | Acero

6 | 1 | 2026-06-25-04-22-19-951 | Acero

Dept. | Technical reference | Created by javier fuentes 25-06-2026 | Approved by

Document type | Document status

Title Caja Javi | DWG No.

Rev. | Date of issue | Sheet

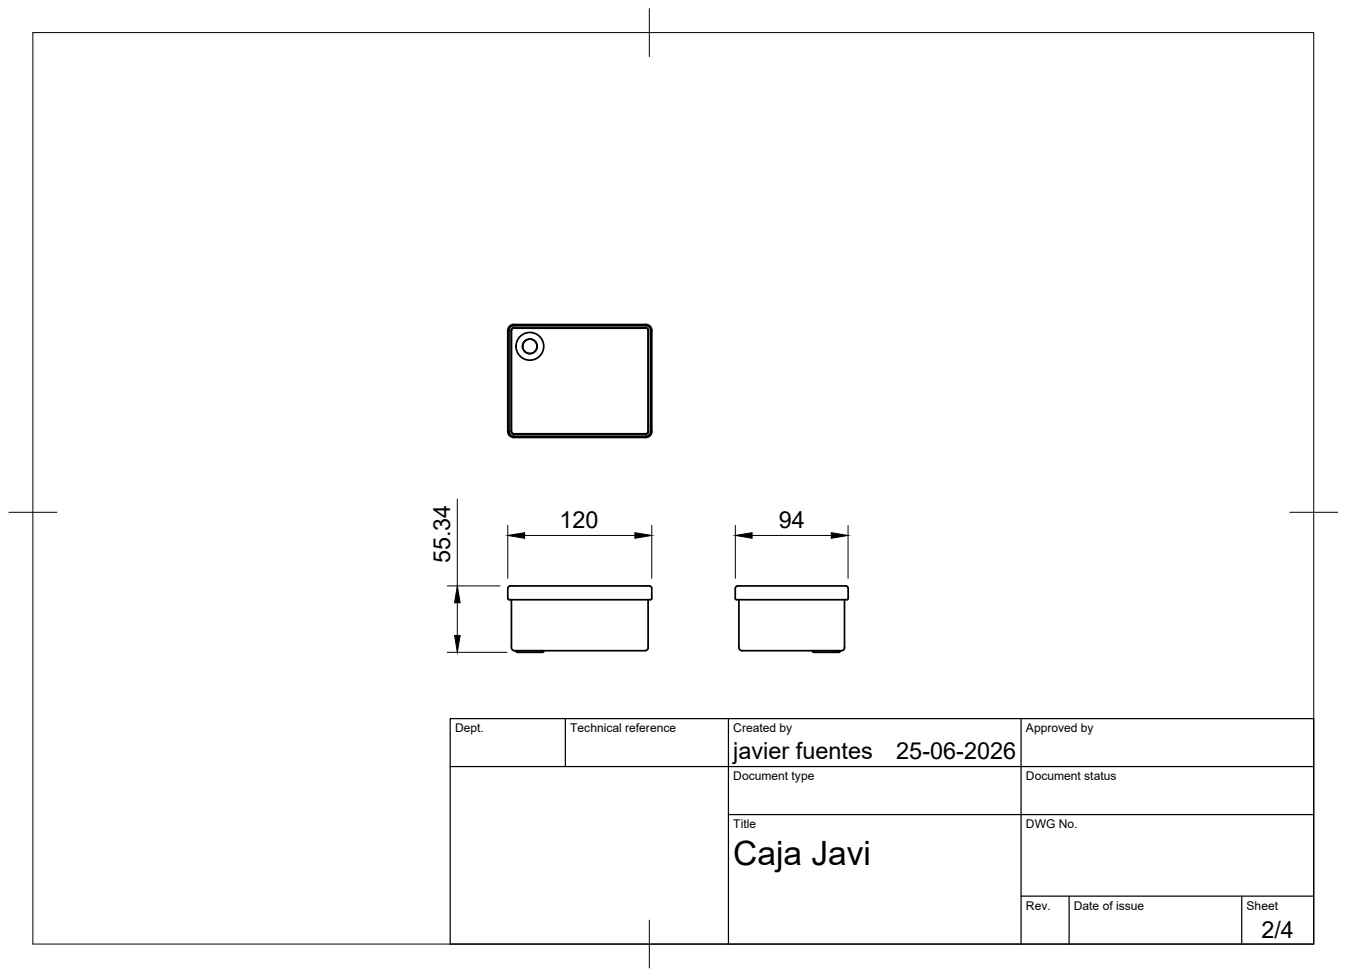
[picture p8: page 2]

Dept. | Technical reference | Created by javier fuentes 25-06-2026 | Approved by

Document type | Document status

Title Caja Javi | DWG No.

Rev. | Date of issue | Sheet

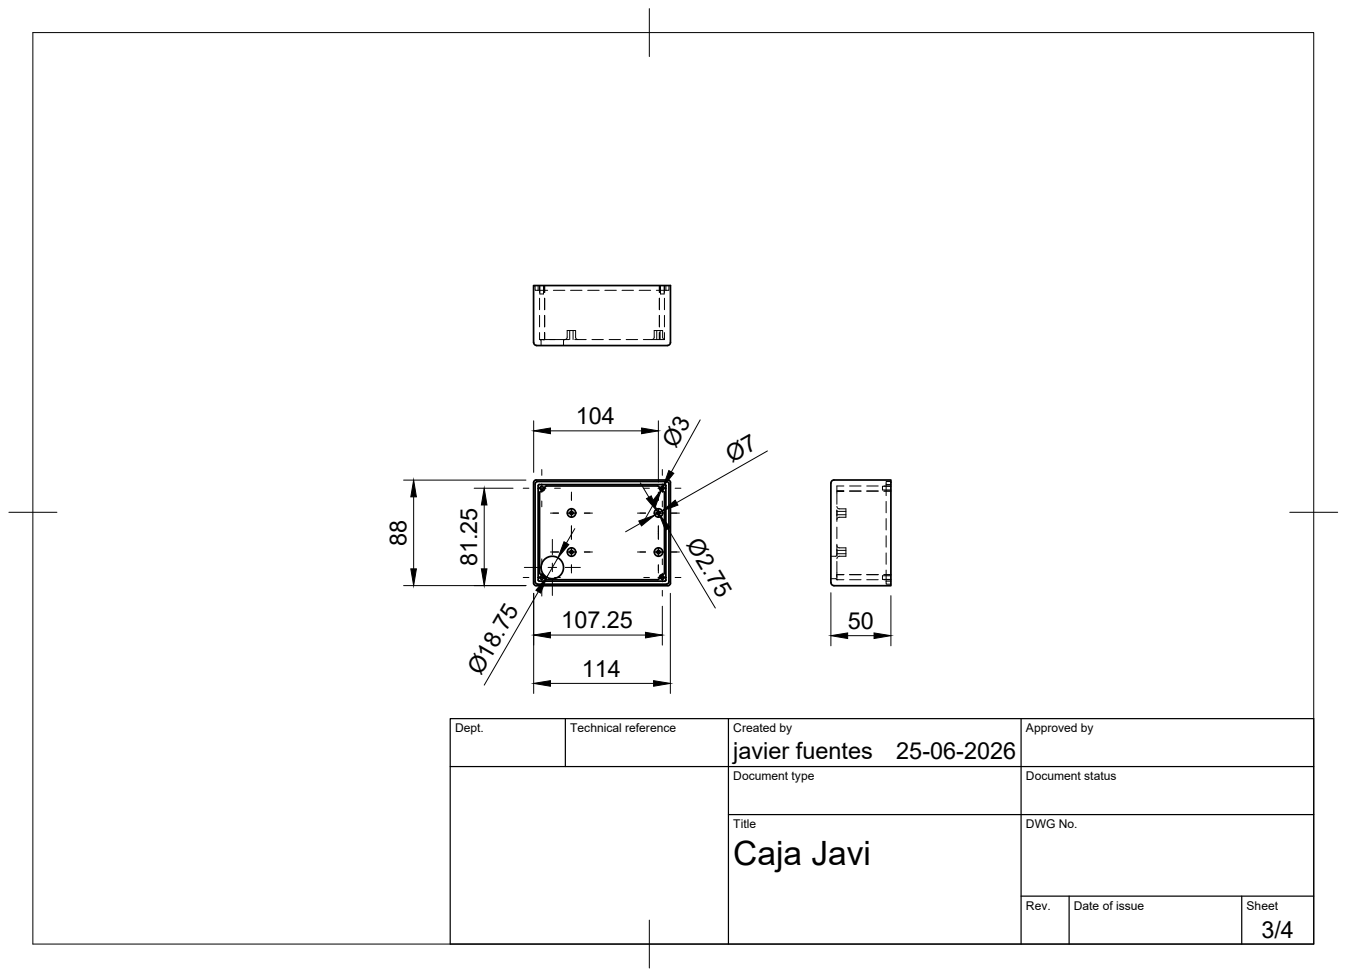
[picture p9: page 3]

Dept. | Technical reference | Created by javier fuentes 25-06-2026 | Approved by

Document type | Document status

Title Caja Javi | DWG No.

Rev. | Date of issue | Sheet

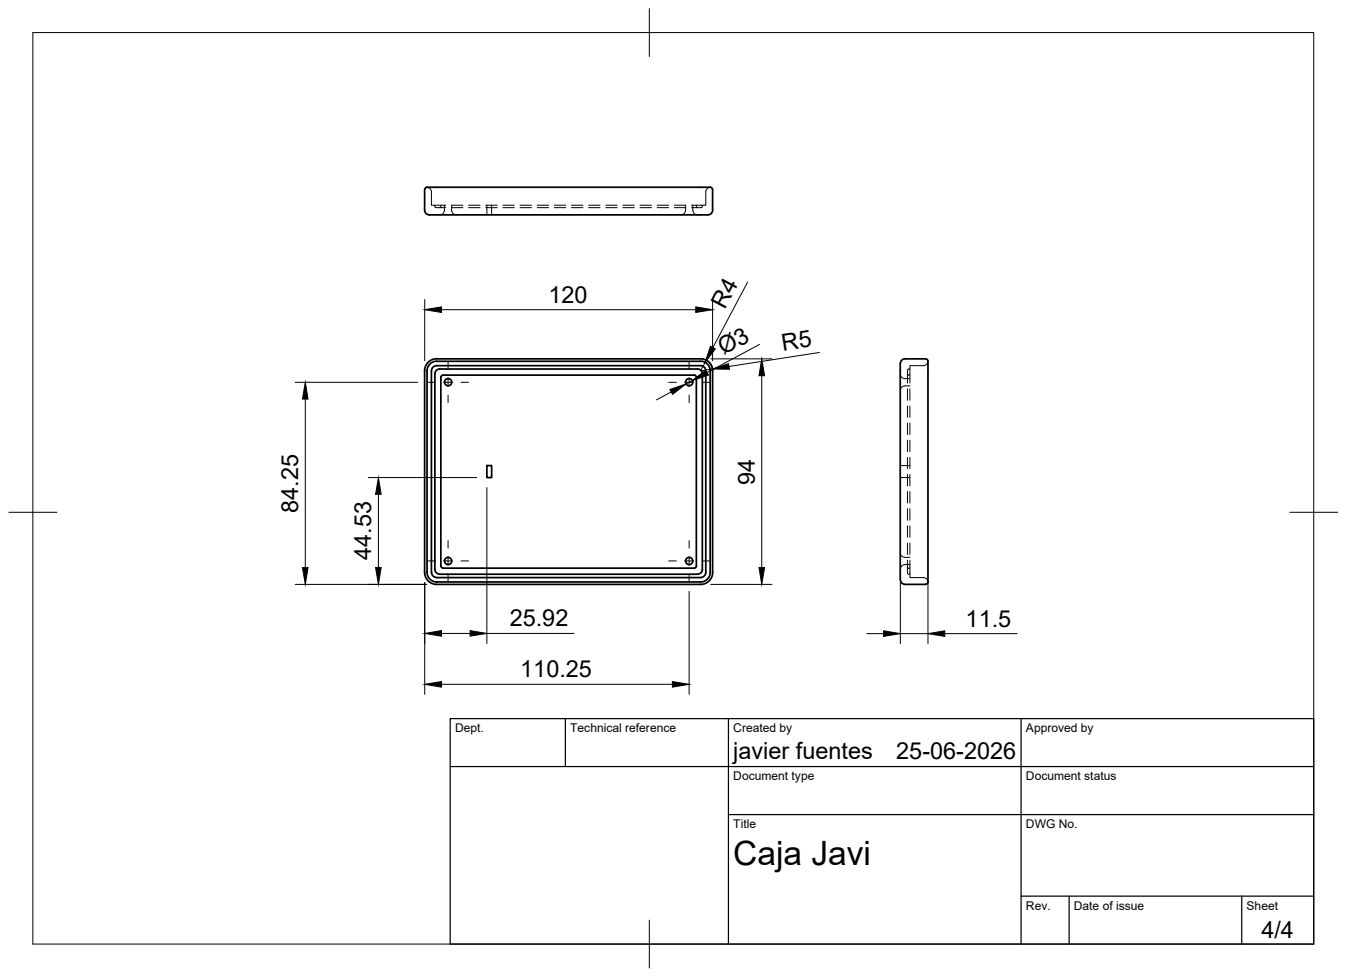
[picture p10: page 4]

Dept. | Technical reference | Created by javier fuentes 25-06-2026 | Approved by

Document type | Document status

Title Caja Javi | DWG No.

Rev. | Date of issue | Sheet

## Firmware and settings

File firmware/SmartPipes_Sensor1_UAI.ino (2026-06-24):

#include <WiFi.h>
#include <HTTPClient.h>
#include <WiFiClientSecure.h>

// =====================================================
// SMART PIPES
// ESP32-S3 + SENSOR ULTRASONICO SR04M-2 + SENSOR HUMEDAD
// VERSION SIN OLED
// ENVIA DATOS A DASHBOARD WEB EN RAILWAY
// =====================================================


// =====================================================
// 1. IDENTIFICACION DEL SENSOR
// =====================================================

// Este numero identifica el sensor dentro de la base de datos.
// En el dashboard aparece como "Sensor 1 UAI".
#define NODO_ID 1


// =====================================================
// 2. CALIBRACION FISICA DE LA ALCANTARILLA
// =====================================================

// Distancia medida cuando la alcantarilla esta limpia.
// Como la alcantarilla limpia mide aprox 1 metro,
// dejamos 100 cm como referencia de 0% lleno.
#define DISTANCIA_LIMPIA_CM 100.0

// Distancia medida cuando la alcantarilla esta casi tapada.
// Mientras menor es la distancia, mas cerca esta el agua/basura/sedimento del sensor.
// Dejamos 20 cm como referencia de 100% lleno.
#define DISTANCIA_TAPADA_CM 20.0

/*
  Interpretacion general:

  100 cm o mas = alcantarilla limpia = 0% lleno
  20 cm o menos = alcantarilla tapada = 100% lleno

  El sensor mide distancia desde arriba hacia abajo.

  Si la distancia es grande:
  - El fondo esta lejos.
  - Hay poco material acumulado.
  - El sistema esta normal.

  Si la distancia es chica:
  - El material esta cerca del sensor.
  - Hay acumulacion, agua o basura.
  - El sistema esta en alerta o emergencia.
*/


// =====================================================
// 3. DATOS WIFI
// =====================================================

// Nombre de la red WiFi.
// Ojo: tu red tiene un punto al final.
const char* WIFI_SSID = "iPhone de javier.";

// Clave WiFi.
const char* WIFI_PASSWORD = "123456789";


// =====================================================
// 4. API RAILWAY
// =====================================================

// URL publica de la API.
// La ESP32 envia aqui las mediciones.
// Railway las guarda en la base de datos Aiven.
const char* API_URL = "https://smartpipes-api-production.up.railway.app/api/mediciones";


// =====================================================
// 5. PINES
// =====================================================

// Sensor ultrasonico SR04M-2 / AJ-SR04M:
// Conexion usada:
// 5V sensor  -> 5V/VIN ESP32
// GND sensor -> GND ESP32
// TX sensor  -> GPIO18 ESP32
// RX sensor  -> sin conectar
const int echoPin = 18;


// Sensor humedad / lluvia de 2 pines:
// Conexion recomendada:
// Un pin del sensor -> 3V3
// Otro pin del sensor -> GPIO4
// GPIO4 -> resistencia 10k -> GND
//
// La resistencia 10k es importante porque evita falsos positivos.
// Sin resistencia, GPIO4 queda flotando y puede marcar humedad falsa.
const int rainPin = 4;


// Umbral de humedad.
// Se ajusta mirando el monitor serial.
// Si seco da bajo y mojado da alto, se usa valor > 1500.
// Si seco da alto y mojado da bajo, se invierte en leerLluvia().
#define UMBRAL_LLUVIA 1500


// =====================================================
// 6. ESTRUCTURA DE ESTADO
// =====================================================

// Esta estructura guarda el estado calculado del alcantarillado.
struct Estado {
  String nombre;          // NORMAL, ATENCION, ALERTA, RIESGO, CRITICO, EMERGENCIA, ERROR
  String interpretacion;  // Texto corto explicativo
  int nivel;              // Nivel numerico de gravedad: 0 a 5
};


// =====================================================
// 7. CALCULAR PORCENTAJE DE LLENADO
// =====================================================

float calcularPorcentajeLleno(float distancia) {

  // Si la distancia es negativa, significa error de lectura.
  if (distancia < 0) {
    return -1;
  }

  /*
    Formula:

    porcentaje = (distancia limpia - distancia actual)
                 -------------------------------------- x 100
                 (distancia limpia - distancia tapada)

    Con nuestra calibracion:

    distancia limpia = 100 cm
    distancia tapada = 20 cm

    Ejemplos:

    distancia = 100 cm:
    porcentaje = 0%

    distancia = 60 cm:
    porcentaje = 50%

    distancia = 20 cm:
    porcentaje = 100%
  */

  float porcentaje = ((DISTANCIA_LIMPIA_CM - distancia) /
                     (DISTANCIA_LIMPIA_CM - DISTANCIA_TAPADA_CM)) * 100.0;

  // Si mide mas de 100 cm, puede dar negativo.
  // Lo dejamos como 0%.
  if (porcentaje < 0) {
    porcentaje = 0;
  }

  // Si mide menos de 20 cm, puede dar mas de 100.
  // Lo dejamos como 100%.
  if (porcentaje > 100) {
    porcentaje = 100;
  }

  return porcentaje;
}


// =====================================================
// 8. EVALUAR ESTADO CON DISTANCIA + PORCENTAJE
// =====================================================

Estado evaluarEstado(float distancia, float porcentaje) {
  Estado e;

  /*
    Esta funcion usa DOS criterios:

    1. Distancia fisica en centimetros:
       Indica que tan cerca esta la obstruccion del sensor.

    2. Porcentaje de llenado:
       Indica que tan llena esta la alcantarilla respecto a la calibracion.

    Mientras menor es la distancia, peor.
    Mientras mayor es el porcentaje, peor.
  */

  // Error de sensor.
  if (distancia < 0 || porcentaje < 0) {
    e.nombre = "ERROR";
    e.interpretacion = "Falla sensor";
    e.nivel = -1;
  }

  // EMERGENCIA:
  // Distancia <= 30 cm o porcentaje >= 90%.
  // El material esta muy cerca del sensor.
  else if (distancia <= 30 || porcentaje >= 90) {
    e.nombre = "EMERGENCIA";
    e.interpretacion = "Tapado total";
    e.nivel = 5;
  }

  // CRITICO:
  // Distancia <= 45 cm o porcentaje >= 75%.
  // La alcantarilla esta casi colapsada.
  else if (distancia <= 45 || porcentaje >= 75) {
    e.nombre = "CRITICO";
    e.interpretacion = "Casi colapsado";
    e.nivel = 4;
  }

  // RIESGO:
  // Distancia <= 60 cm o porcentaje >= 60%.
  // Hay obstruccion alta.
  else if (distancia <= 60 || porcentaje >= 60) {
    e.nombre = "RIESGO";
    e.interpretacion = "Obstruccion alta";
    e.nivel = 3;
  }

  // ALERTA:
  // Distancia <= 80 cm o porcentaje >= 40%.
  // Puede existir bloqueo parcial.
  else if (distancia <= 80 || porcentaje >= 40) {
    e.nombre = "ALERTA";
    e.interpretacion = "Posible bloqueo";
    e.nivel = 2;
  }

  // ATENCION:
  // Distancia menor a 100 cm o porcentaje >= 20%.
  // Hay acumulacion leve.
  else if (distancia < 100 || porcentaje >= 20) {
    e.nombre = "ATENCION";
    e.interpretacion = "Acumulacion leve";
    e.nivel = 1;
  }

  // NORMAL:
  // Distancia >= 100 cm y porcentaje menor a 20%.
  else {
    e.nombre = "NORMAL";
    e.interpretacion = "Ducto despejado";
    e.nivel = 0;
  }

  return e;
}


// =====================================================
// 9. MEDIR DISTANCIA UNA VEZ
// =====================================================

float medirDistanciaUnaVez() {

  /*
    pulseIn mide cuanto tiempo el GPIO18 esta en HIGH.

    El sensor ultrasonico calcula distancia con el tiempo
    que demora el pulso en volver.

    Timeout = 35000 microsegundos.
    Si no hay lectura, devuelve 0.
  */

  long duracion = pulseIn(echoPin, HIGH, 35000);

  // Si no hubo pulso, devolvemos error.
  if (duracion == 0) {
    return -1;
  }

  /*
    Velocidad del sonido aprox:
    0.034 cm/us

    El sonido va y vuelve, por eso se divide en 2.

    distancia = duracion x 0.034 / 2
  */

  float distancia = duracion * 0.034 / 2.0;

  return distancia;
}


// =====================================================
// 10. MEDIR DISTANCIA PROMEDIO
// =====================================================

float medirDistanciaPromedio() {

  // Tomamos varias mediciones para evitar lecturas locas.
  const int muestras = 5;

  float suma = 0;
  int validas = 0;

  for (int i = 0; i < muestras; i++) {

    float d = medirDistanciaUnaVez();

    // Aceptamos solo mediciones razonables.
    if (d > 0 && d < 600) {
      suma += d;
      validas++;
    }

    delay(100);
  }

  // Si ninguna medicion fue valida, retornamos error.
  if (validas == 0) {
    return -1;
  }

  // Promedio de lecturas validas.
  return suma / validas;
}


// =====================================================
// 11. SENSOR DE HUMEDAD / LLUVIA
// =====================================================

int leerValorLluvia() {

  // Lee el valor analogico del GPIO4.
  // En ESP32 normalmente va de 0 a 4095.
  return analogRead(rainPin);
}


bool leerLluvia() {

  int valor = leerValorLluvia();

  /*
    Con la conexion:
    sensor -> 3V3
    sensor -> GPIO4
    GPIO4 -> resistencia 10k -> GND

    Lo esperado es:
    - Seco/desconectado: valor bajo
    - Mojado/conduciendo: valor alto

    Por eso usamos:
    valor > UMBRAL_LLUVIA

    Si en tu prueba pasa al reves, cambia la linea por:
    return valor < UMBRAL_LLUVIA;
  */

  return valor > UMBRAL_LLUVIA;
}


// =====================================================
// 12. CONECTAR A WIFI
// =====================================================

bool conectarWiFi() {

  Serial.print("Conectando a WiFi: ");
  Serial.println(WIFI_SSID);

  // Modo estacion: la ESP32 se conecta a una red existente.
  WiFi.mode(WIFI_STA);

  // Inicia conexion.
  WiFi.begin(WIFI_SSID, WIFI_PASSWORD);

  int intentos = 0;

  // Espera hasta 15 segundos aprox.
  while (WiFi.status() != WL_CONNECTED && intentos < 30) {
    delay(500);
    Serial.print(".");
    intentos++;
  }

  Serial.println();

  if (WiFi.status() == WL_CONNECTED) {
    Serial.println("WiFi conectado correctamente");
    Serial.print("IP ESP32: ");
    Serial.println(WiFi.localIP());
    return true;
  } else {
    Serial.println("No se pudo conectar a WiFi");
    return false;
  }
}


// =====================================================
// 13. ENVIAR DATOS A RAILWAY
// =====================================================

void enviarDatosAPI(float distancia, float porcentaje, bool lluvia, String estado) {

  // Si se perdio WiFi, intenta reconectar.
  if (WiFi.status() != WL_CONNECTED) {
    Serial.println("WiFi desconectado. Reintentando...");

    if (!conectarWiFi()) {
      Serial.println("No se pudo enviar porque no hay WiFi");
      return;
    }
  }

  /*
    Como la URL es HTTPS, usamos WiFiClientSecure.

    client.setInsecure() evita problemas de certificado SSL.
    Para prototipo universitario esta bien.
  */

  WiFiClientSecure client;
  client.setInsecure();

  HTTPClient http;

  Serial.print("Enviando datos a API: ");
  Serial.println(API_URL);

  // Inicia conexion HTTPS.
  http.begin(client, API_URL);

  // Indicamos que el contenido enviado es JSON.
  http.addHeader("Content-Type", "application/json");

  /*
    JSON enviado a la API.

    La base de datos guarda:
    - nodo_id
    - distancia_cm
    - porcentaje_lleno
    - humedad
    - estado
    - bateria_voltaje

    Por ahora bateria_voltaje queda fijo en 3.70.
    Cuando agreguemos medicion real de bateria, se reemplaza.
  */

  String json = "{";
  json += "\"nodo_id\":" + String(NODO_ID) + ",";
  json += "\"distancia_cm\":" + String(distancia, 1) + ",";
  json += "\"porcentaje_lleno\":" + String(porcentaje, 1) + ",";
  json += "\"humedad\":" + String(lluvia ? "true" : "false") + ",";
  json += "\"estado\":\"" + estado + "\",";
  json += "\"bateria_voltaje\":3.70";
  json += "}";

  Serial.println("JSON enviado:");
  Serial.println(json);

  // Envia los datos usando POST.
  int codigoRespuesta = http.POST(json);

  Serial.print("Codigo respuesta API: ");
  Serial.println(codigoRespuesta);

  // Respuesta que manda Railway.
  String respuesta = http.getString();

  Serial.println("Respuesta API:");
  Serial.println(respuesta);

  // Cierra conexion.
  http.end();
}


// =====================================================
// 14. IMPRIMIR EN MONITOR SERIAL
// =====================================================

void imprimirSerial(float distancia, float porcentaje, bool lluvia, int valorLluvia, Estado estado) {

  Serial.println();
  Serial.println("========== SMART PIPES ==========");

  Serial.print("Sensor: ");
  Serial.print(NODO_ID);
  Serial.println(" UAI");

  Serial.println("---------------------------------");

  Serial.print("Distancia fisica medida: ");

  if (distancia < 0) {
    Serial.println("ERROR");
  } else {
    Serial.print(distancia, 1);
    Serial.println(" cm");
  }

  Serial.print("Porcentaje de llenado: ");

  if (porcentaje < 0) {
    Serial.println("ERROR");
  } else {
    Serial.print(porcentaje, 1);
    Serial.println(" %");
  }

  Serial.println("---------------------------------");

  Serial.print("Valor humedad ADC: ");
  Serial.println(valorLluvia);

  Serial.print("Humedad detectada: ");
  Serial.println(lluvia ? "SI" : "NO");

  Serial.println("---------------------------------");

  Serial.print("Estado: ");
  Serial.println(estado.nombre);

  Serial.print("Interpretacion: ");
  Serial.println(estado.interpretacion);

  Serial.print("Nivel visual: ");

  int nivelSeguro = estado.nivel;

  if (nivelSeguro < 0) {
    nivelSeguro = 0;
  }

  if (nivelSeguro > 5) {
    nivelSeguro = 5;
  }

  for (int i = 0; i < nivelSeguro; i++) {
    Serial.print("#");
  }

  for (int i = nivelSeguro; i < 5; i++) {
    Serial.print("-");
  }

  Serial.println();

  Serial.println("---------------------------------");

  Serial.println("Criterio de distancia:");
  Serial.println(">= 100 cm  -> NORMAL");
  Serial.println("< 100 cm   -> ATENCION");
  Serial.println("<= 80 cm   -> ALERTA");
  Serial.println("<= 60 cm   -> RIESGO");
  Serial.println("<= 45 cm   -> CRITICO");
  Serial.println("<= 30 cm   -> EMERGENCIA");

  Serial.println("---------------------------------");

  Serial.println("Criterio de porcentaje:");
  Serial.println("0% - 19%   -> NORMAL");
  Serial.println("20% - 39%  -> ATENCION");
  Serial.println("40% - 59%  -> ALERTA");
  Serial.println("60% - 74%  -> RIESGO");
  Serial.println("75% - 89%  -> CRITICO");
  Serial.println("90% - 100% -> EMERGENCIA");

  Serial.println("=================================");
}


// =====================================================
// 15. SETUP
// =====================================================

void setup() {

  // Inicia comunicacion serial.
  Serial.begin(115200);

  // Espera 1 segundo para que el monitor serial cargue.
  delay(1000);

  // Configura el pin del sensor ultrasonico.
  pinMode(echoPin, INPUT);

  // Configura el pin del sensor de humedad.
  pinMode(rainPin, INPUT);

  Serial.println("=================================");
  Serial.println(" SMART PIPES INICIADO");
  Serial.println(" VERSION SIN OLED");
  Serial.println(" CALIBRACION A 1 METRO");
  Serial.println("=================================");

  Serial.println("Sensor distancia:");
  Serial.println("5V sensor ultrasonico -> 5V/VIN ESP32");
  Serial.println("GND sensor ultrasonico -> GND ESP32");
  Serial.println("TX sensor ultrasonico -> GPIO18 ESP32");
  Serial.println("RX sensor ultrasonico -> sin conectar");

  Serial.println();

  Serial.println("Sensor humedad:");
  Serial.println("Un pin sensor humedad -> 3V3");
  Serial.println("Otro pin sensor humedad -> GPIO4");
  Serial.println("GPIO4 -> resistencia 10k -> GND");

  Serial.println();

  Serial.println("Calibracion fisica:");
  Serial.print(DISTANCIA_LIMPIA_CM);
  Serial.println(" cm o mas = alcantarilla limpia = 0%");
  Serial.print(DISTANCIA_TAPADA_CM);
  Serial.println(" cm o menos = alcantarilla tapada = 100%");

  Serial.println();

  Serial.println("API:");
  Serial.println(API_URL);

  Serial.println("=================================");

  // Intenta conectar a WiFi.
  conectarWiFi();
}


// =====================================================
// 16. LOOP PRINCIPAL
// =====================================================

void loop() {

  // 1. Medir distancia fisica desde el sensor hasta el fondo/obstruccion.
  float distancia = medirDistanciaPromedio();

  // 2. Leer valor crudo del sensor de humedad.
  int valorLluvia = leerValorLluvia();

  // 3. Convertir humedad a SI/NO segun el umbral.
  bool lluvia = leerLluvia();

  // 4. Calcular porcentaje de llenado usando 100 cm como limpio y 20 cm como tapado.
  float porcentaje = calcularPorcentajeLleno(distancia);

  // 5. Evaluar estado usando distancia fisica y porcentaje.
  Estado estado = evaluarEstado(distancia, porcentaje);

  // 6. Mostrar todo en monitor serial.
  imprimirSerial(distancia, porcentaje, lluvia, valorLluvia, estado);

  // 7. Enviar distancia, porcentaje, humedad y estado a Railway.
  enviarDatosAPI(distancia, porcentaje, lluvia, estado.nombre);

  // 8. Esperar 10 segundos.
  // Para pruebas esta bien.
  // Para version con bateria despues usamos deep sleep.
  delay(10000);
}

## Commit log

2026-06-23 Agregar historico por sensor
    Added a new endpoint to fetch historical sensor data by month and sensor ID, updated existing comments, and increased the limit for recent measurements.
2026-06-24 Agregar firmware del sensor 1 UAI
2026-06-24 Agregar firmware del sensor 1 UAI
    This file implements the Smart Pipes sensor functionality, including WiFi connection, distance measurement, humidity detection, and data transmission to a web API.
2026-06-24 Agregar BOM SmartPipes
2026-06-24 Agregar BOM SmartPipes
    This document summarizes the components used to build the SmartPipes prototype, including specifications and approximate costs.
2026-06-24 ```txt Agregar esquematico de conexiones
    Added detailed connection schematic for SmartPipes system, including components and wiring instructions.
2026-06-25 Agregar esquematico de conexiones
2026-06-25 Actualizar README con documentación de hardware
    Added detailed hardware documentation and file descriptions.
2026-06-25 Agregar protocolo y validacion de pruebas
2026-06-25 Agregar protocolo y validacion de pruebas
    Document the protocol, results analysis, and validation for the SmartPipes IoT system, detailing objectives, testing conditions, procedures, results, and conclusions.
2026-06-25 Update humidity interpretation in validation protocol
    Clarify the role of humidity in duct status evaluation.
2026-06-25 Crear registro pruebas
    [registro_pruebas.csv]
2026-06-25 Crear readme Firmware
    Added detailed README for SmartPipes firmware, outlining functionality, calibration, hardware requirements, and usage instructions.
2026-06-25 Update Readme.md
    Expanded the hardware documentation for SmartPipes, detailing components, schematics, architecture, and technical considerations. Added sections on BOM, connections, and general justification of hard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
2026-06-25 Update Readme.md
    Updated README.md to provide detailed information about the 3D design files for the SmartPipes project, including descriptions of the Fusion 360 file, STL file, technical drawings, and the purpose of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
2026-06-25 3D SMART PIPES CARCASA.f3d
    [3D SMART PIPES CARCASA.f3d]
2026-06-25 3D SMART PIPES.stl
    [3D SMART PIPES.stl]
2026-06-25 Rename Encapsulado f3d.step to Encapsulado f3d (online).step
    [Encapsulado f3d (online).step]
